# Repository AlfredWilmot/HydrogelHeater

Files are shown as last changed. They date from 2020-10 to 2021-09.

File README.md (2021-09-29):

# Overview of temperature controller hardware
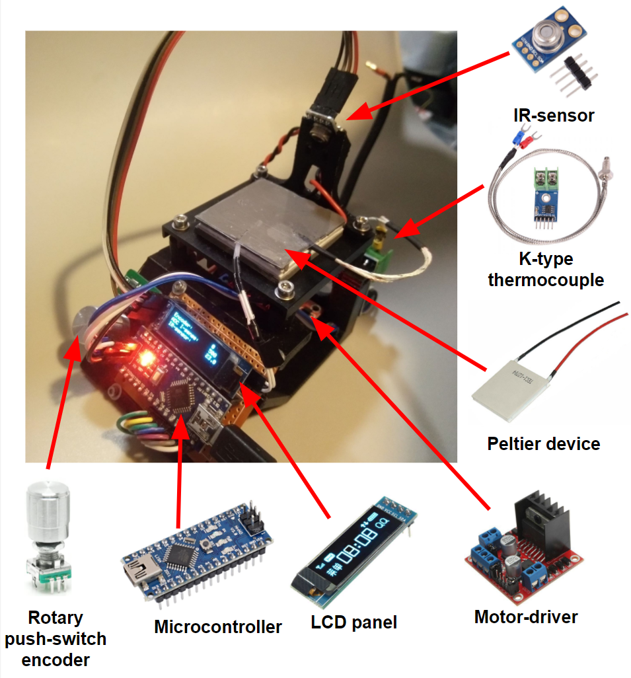
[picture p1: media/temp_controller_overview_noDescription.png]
 

[Click to see video showing visualization of system control varialbles during use.](https://drive.google.com/file/d/1k_EgCX9lhL9ZffbRWtTjD1a9hdL3mkuH/view?usp=sharing)

# Use of temperature controller for stimuli-responsive hydrogel research

| Experimental set-up | Close-up of activated temperature-sensitive hydrogel (20x speed) driven by temperature controller|
---|---
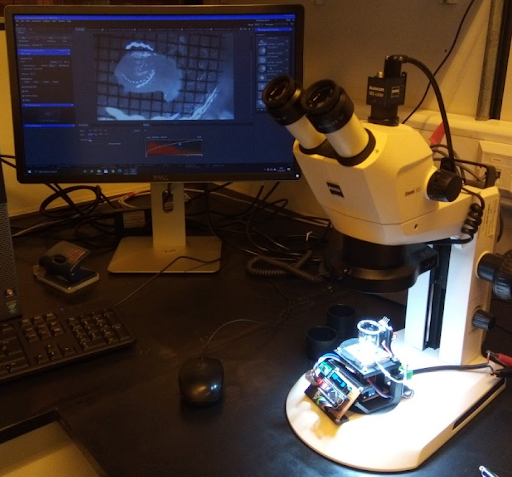
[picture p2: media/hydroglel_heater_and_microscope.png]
 |

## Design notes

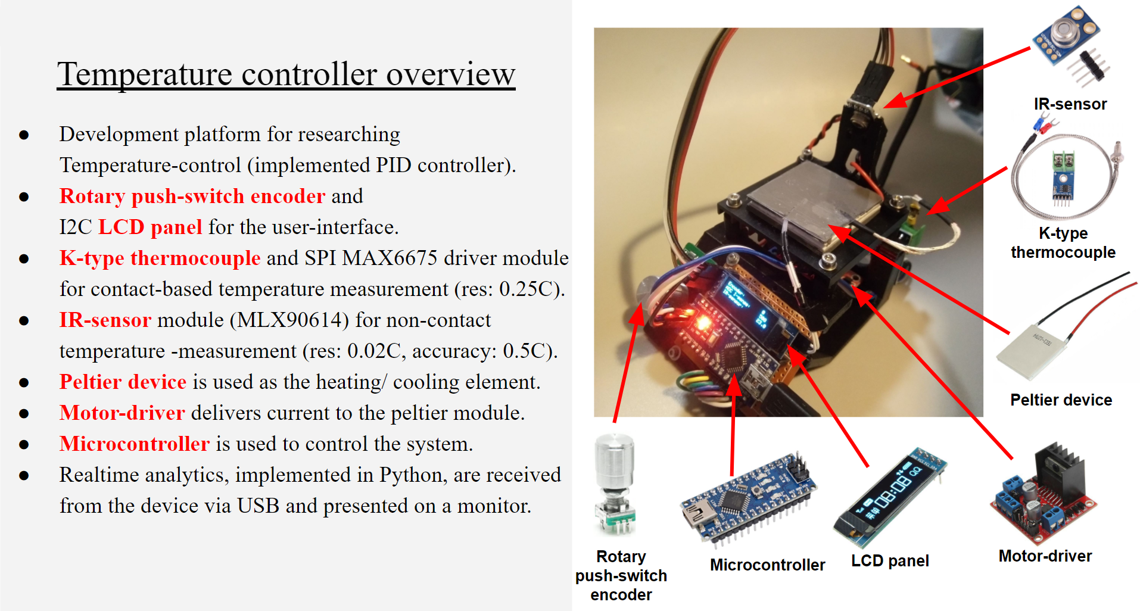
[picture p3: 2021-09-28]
media/temp_controller_overview.png

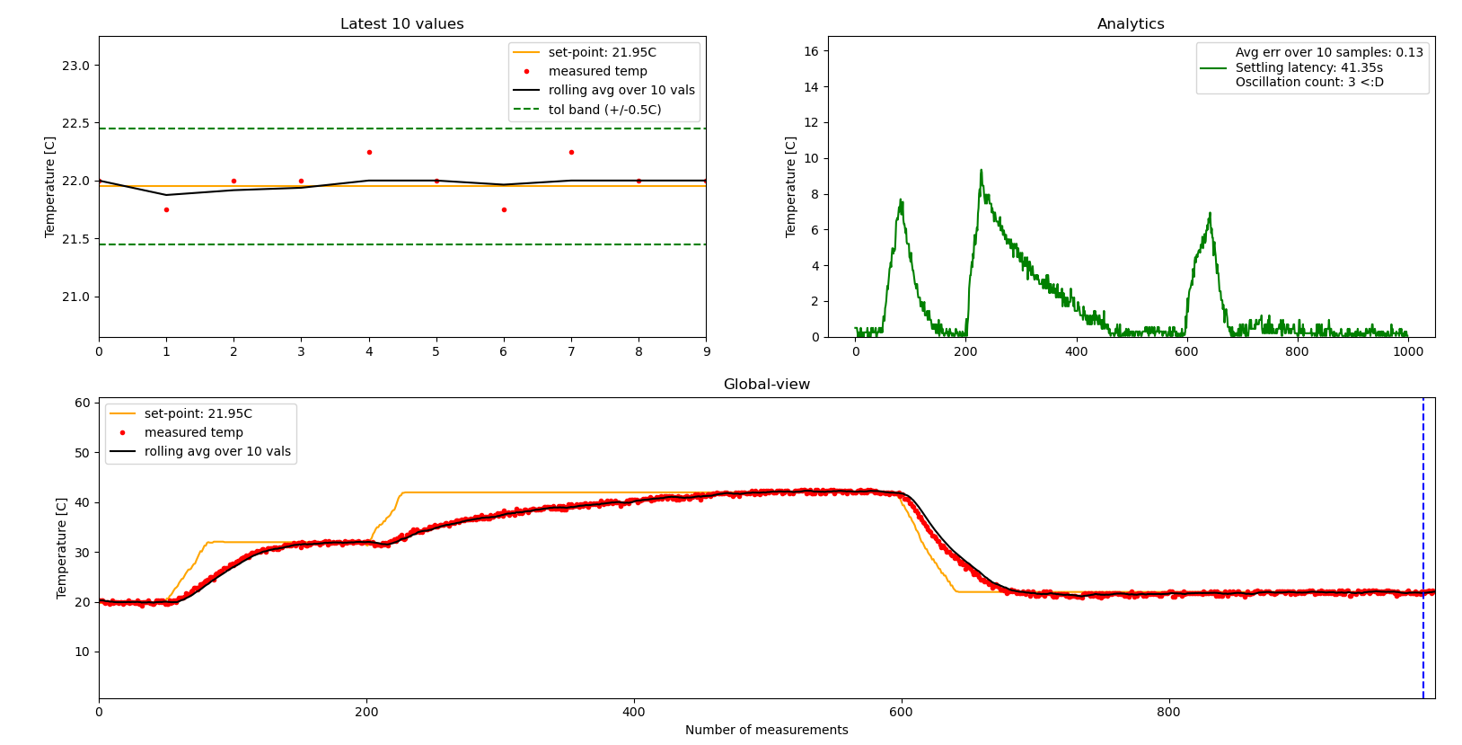
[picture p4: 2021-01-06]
data_analysis/pics/06_01_2021/PID_control_with_k_type.PNG

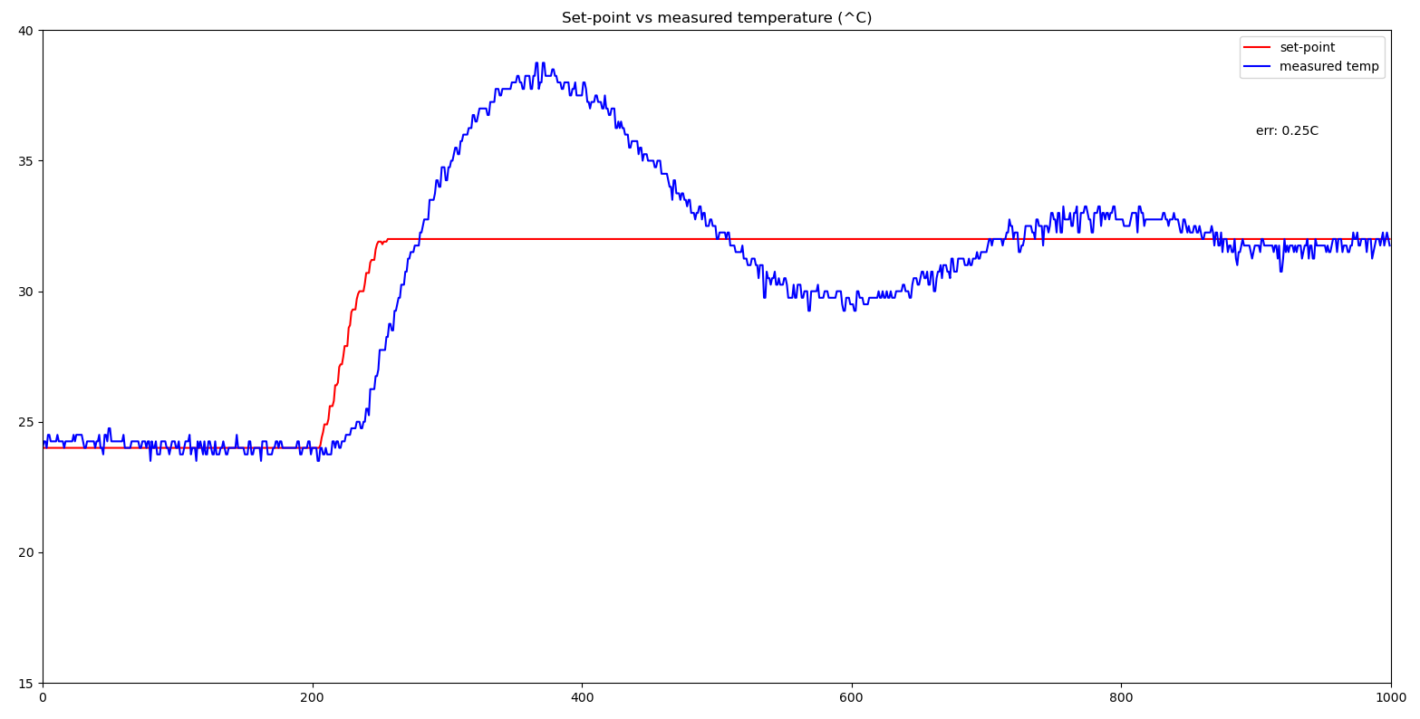
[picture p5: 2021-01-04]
data_analysis/pics/04_01_2021/24_to_32_k_type_cumulative_err.PNG

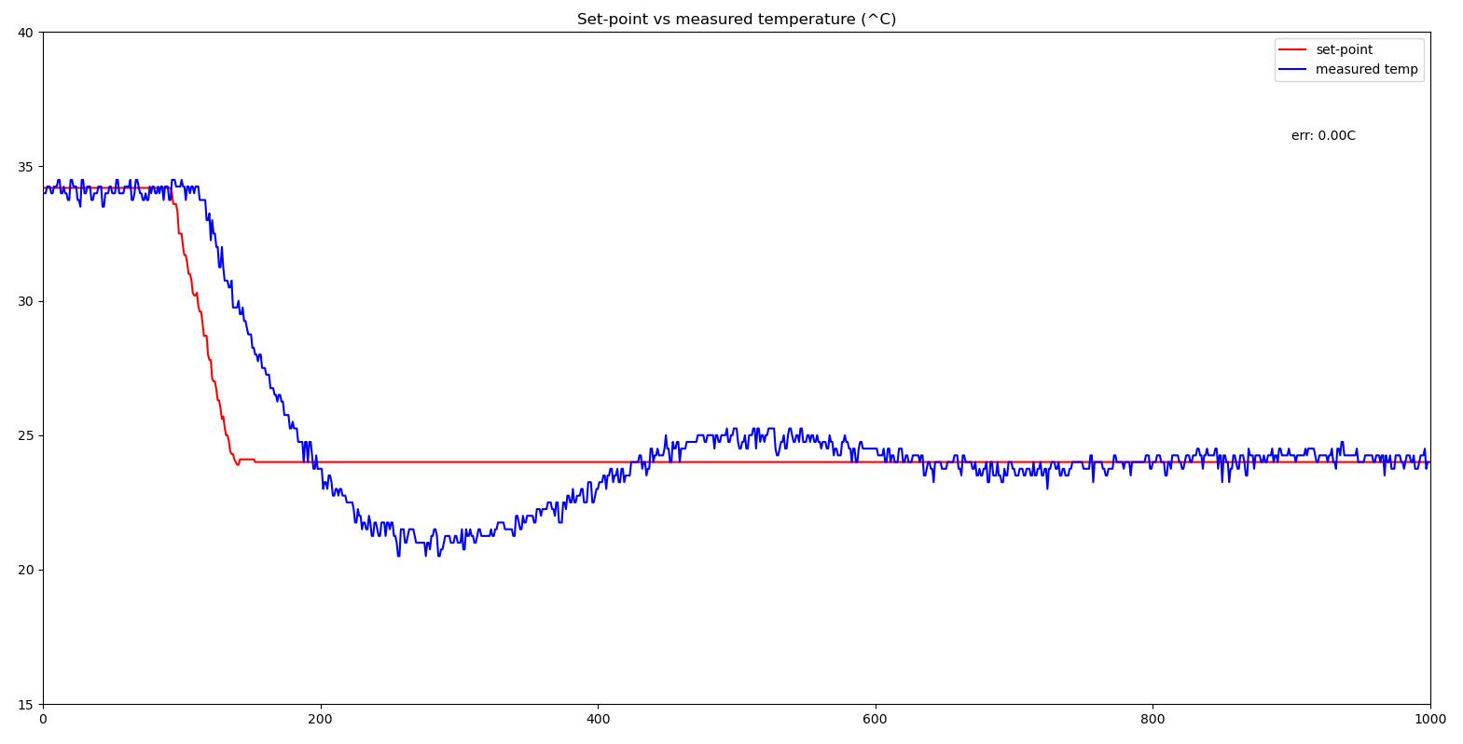
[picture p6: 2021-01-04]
data_analysis/pics/04_01_2021/32_to_24_k_type_cumulative_err.PNG

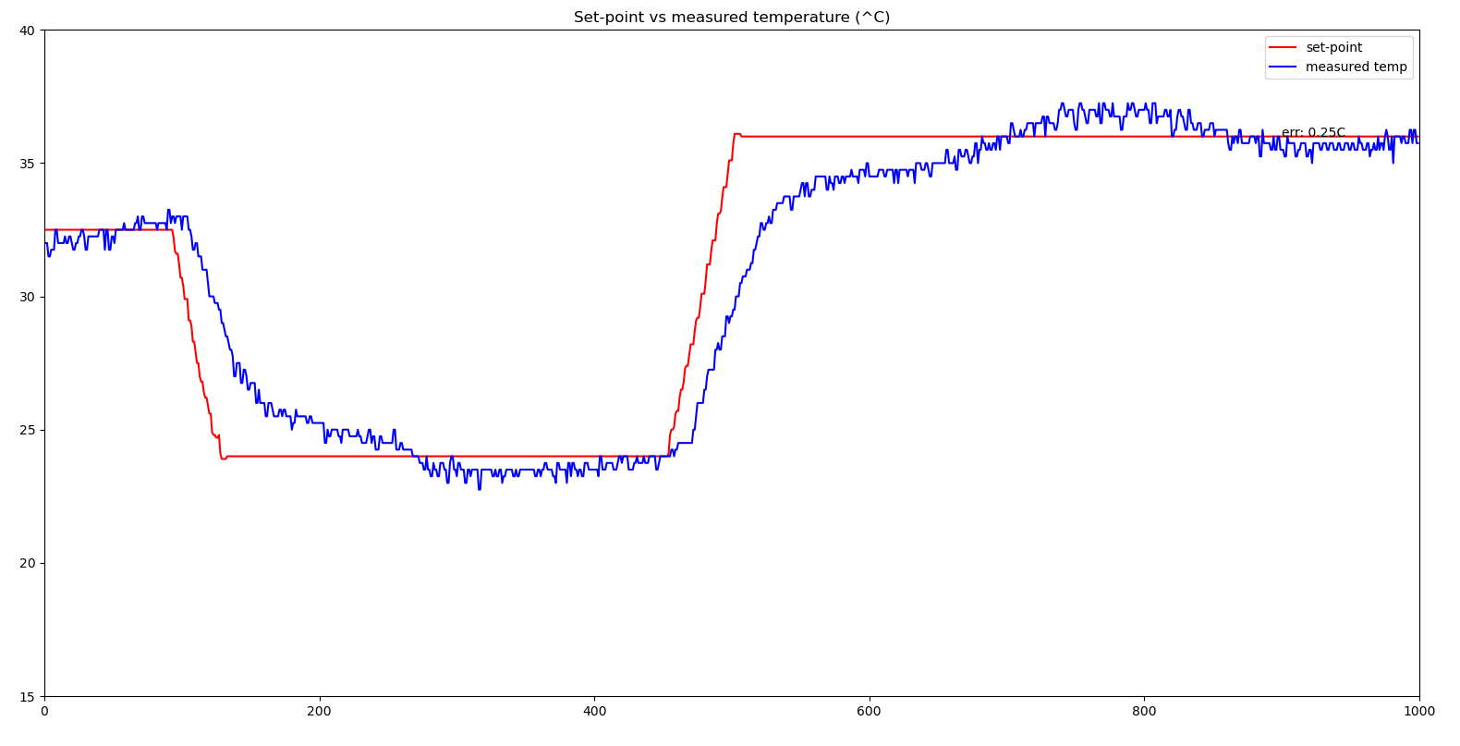
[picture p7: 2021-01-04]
data_analysis/pics/04_01_2021/32_to_24_to_36_kType_ImprovedCumulativeErr.PNG

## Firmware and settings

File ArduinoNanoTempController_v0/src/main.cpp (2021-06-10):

#include <Arduino.h>
#include "my_sensors.h"
#include "Adafruit_SSD1306.h"
#include "Adafruit_GFX.h"

// I2C IR sensor libs
#include "Wire.h"
#include "Adafruit_MLX90614.h"
/* Reference code taken from: https://miliohm.com/non-contact-temperature-sensor-mlx90614-arduino-tutorial/ */
Adafruit_MLX90614 IR_sense = Adafruit_MLX90614();


/*TODO: 
    > Add more indicator LEDs to the board for diagnostics.
    > Can also add information into classes from datasheets to also consider sensor accuracy/ precision.
*/

/* Resources for setting-up Ardunio programming in VS-Code:

-> Tutorial for settin-up PlatformIO for Arduino programming  (https://www.youtube.com/watch?v=dany7ae_0ks) 
-> Explore config files for different MCUs; not jsut Arduino  (https://platformio.org/boards)
-> Config settings for Arduino Nano                           (https://docs.platformio.org/en/latest/boards/atmelavr/nanoatmega328.html)

*/

// Allocating the A0 and A7 ADC pins to the NTC thermistor and I-sense monitor, respectively.
//NTC_thermistor my_ntc(Arduino_h::A0);
//I_sensor INA283(Arduino_h::A7, 10);

// Setup encoder push-button
EncoderPushButton EC11(2,3,4);
void encoder_ISR_handler()
{
  EC11.encoder_handler();
}


//Arduino_h::attachInterrupt(digitalPinToInterrupt(2), EC11.read_encoder_val(), CHANGE);

  //attachInterrupt(digitalPinToInterrupt(IN_B), test, CHANGE);
  //attachInterrupt(digitalPinToInterrupt(SW), test, RISING);


// Setting up the LCD
#define SCREEN_WIDTH 128 // OLED display width, in pixels
#define SCREEN_HEIGHT 32 // OLED display height, in pixels
#define OLED_RESET     4 // Reset pin # (or -1 if sharing Arduino reset pin)
Adafruit_SSD1306 display(SCREEN_WIDTH, SCREEN_HEIGHT, &Wire, OLED_RESET);

// Setting up the pins for the L298N motor-driver (used to drive the peltier element)
#define IN_1 8
#define IN_2 7
#define EN_A 6

// NOTE: switched pins 10 and 9 in code b/c I am too lazy to change the hardware
#define IN_3 10
#define IN_4 9

// pin 11 is used for SPI, so just couple PWM output of EN_A pin to EN_B (should do this for the IN pins too)
//#define EN_B 11

// Setting up SPI-based K-type thermocouple (uses MAX6675 chip)
K_type_couple MAX6675(MAX6675_CS);


//target temperature designated by the user
float set_point = 0.0;
// read temperature is determined by the sensor being used
float read_temperature = 0.0;

// value used to drive the output current through the peltier device [0,255]
int output_signal = 0;

// other menu control variables
int toggle_sense = 0;
int prev_state = EC11.get_state();


              


/* ------------------------------------------------------------------------------------------- */
/* -------------------------------------- ONE-TIME SETUP-------------------------------------- */
/* ------------------------------------------------------------------------------------------- */
void setup()
{

  // setup bottom peltier device
  pinMode(EN_A,OUTPUT);
  pinMode(IN_1,OUTPUT);
  pinMode(IN_2,OUTPUT);

  // setup top peltier device
  pinMode(IN_3,OUTPUT);
  pinMode(IN_4,OUTPUT);

  // Setup serial comms.
  Serial.begin(9600);
  pinMode(LED_BUILTIN,OUTPUT);

  // I2C preamble for OLED display.
  if(!display.begin(SSD1306_SWITCHCAPVCC, 0x3C)) { // Address 0x3C for 128x32
    Serial.println(F("SSD1306 allocation failed"));
    for(;;); // Don't proceed, loop forever
  }

  // Preparing display
  display.display();
  delay(1000);
  display.clearDisplay();
  display.setTextSize(1);
  display.setTextColor(SSD1306_WHITE); // Draw white text
  display.setCursor(0, 0);     // Start at top-left corner
  //display.cp437(true);         // Use full 256 char 'Code Page 437' font


  //set up Interrupts on encoder pins
  attachInterrupt(digitalPinToInterrupt(2), encoder_ISR_handler, CHANGE);
  attachInterrupt(digitalPinToInterrupt(3), encoder_ISR_handler, CHANGE); 
  attachInterrupt(digitalPinToInterrupt(4), encoder_ISR_handler, CHANGE); 
  //initialize the setpoint to equal the ambient temperature of the thermocouple.
  set_point = MAX6675.read();

}

/* ------------------------------------------------------------------------------------------- */
/* ---------------------------------------- MAIN LOOP ---------------------------------------- */
/* ------------------------------------------------------------------------------------------- */
void loop()
{

  // sample the encoder counter so the SP can be adjusted in steps of 0.1C.
  set_point += float(EC11.get_turn_count())/10;

  // threshold the set-point
  set_point > 100 ? set_point = 100: set_point = set_point;
  set_point < 0 ? set_point = 0: set_point = set_point;
  
  
  /*
    ----
    MENU
    ----

    > Overview screen
    > encoder button press -> go to "config submenu" -> can configure temperature sensor used, temperature resolution (fine [0.1], coarse [1.0], v_coarse [5.0]), adjust PID params.
    > Rotate encoder (adjusts set-point based on variables set in the config menu)
  
  */


  /*Display analytics*/ 
  // show data on OLED 128x32 display
  display.clearDisplay();

  display.setCursor(0, 0);
  display.print("Encoder: ");
  display.setCursor(100, 0);
  display.print(set_point,1);

  // display.setCursor(0, 10);
  // display.print("ADC I-sense: ");
  // display.setCursor(100, 10);
  // display.print(int(INA283.read()));

  display.setCursor(0, 10);
  display.print("Driving signal: ");
  display.setCursor(100, 10);
  display.print(output_signal);


  if (EC11.get_state() == btn_push and prev_state != btn_push)
  {
    toggle_sense^=1;
    prev_state = btn_push;
  }
  else if (EC11.get_state() != btn_push)
  {
    prev_state = EC11.get_state();
  }
  
  if (toggle_sense)
  {
  display.setCursor(0, 20);
  display.print("IR-sensor: ");
  display.setCursor(100, 20);
  read_temperature = IR_sense.readObjectTempC();
  display.print(read_temperature, 1);
  }
  else
  {
  display.setCursor(0, 20);
  display.print("k-type: ");
  display.setCursor(100, 20);
  read_temperature = MAX6675.read();
  display.print(read_temperature,1);
  }
  
  display.display(); 


  /*-------------------*/
  /* MAIN CONTROL LOOP */
  /*-------------------*/

  //output_signal = rolling_average_controller(set_point, read_temperature);
  //output_signal = cumulative_error_compensation(set_point, read_temperature);
  output_signal = PID_loop(set_point, read_temperature);

  //move motor CW if encoder val > 0, CCW if < 0, and stop if == 0.
  if (output_signal > 0)
  {
    digitalWrite(IN_1, HIGH);
    digitalWrite(IN_2, LOW);
    digitalWrite(IN_3, HIGH);
    digitalWrite(IN_4, LOW);
  }
  else if (output_signal < 0)
  {
    digitalWrite(IN_1, LOW);
    digitalWrite(IN_2, HIGH);
    digitalWrite(IN_3, LOW);
    digitalWrite(IN_4, HIGH);
  }
  else
  {
    digitalWrite(IN_1, LOW);
    digitalWrite(IN_2, LOW);
    digitalWrite(IN_3, LOW);
    digitalWrite(IN_4, LOW);
  }
  

  // feed current to peltier device
  analogWrite(EN_A, abs(output_signal));
  
  //transmit data over serial port
  Serial.println(set_point);
  Serial.println(read_temperature);
  Serial.println(output_signal);
  }

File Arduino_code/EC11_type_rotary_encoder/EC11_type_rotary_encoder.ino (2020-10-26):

/*
  Rotary encoder used:
  https://tech.alpsalpine.com/prod/e/html/encoder/incremental/ec11/ec11b15242b1.html

  Reference material:
  https://dronebotworkshop.com/rotary-encoders-arduino/
  
*/

// rotary encocer pins
#define IN_A 2  //pulse-train A
#define IN_B 3  //pulse-train B
#define SW 4    //momentary switch, D4
#define LED 13    //on-board indicator LED

int count = 0;  //count pulses
int IN_A_new;   
int IN_A_old;

void setup() {
  
  //configuring internal pup resistors (20k to 5V)
  pinMode(SW, INPUT_PULLUP); 
  pinMode(IN_A, INPUT_PULLUP); 
  pinMode(IN_B, INPUT_PULLUP); 
  pinMode(LED, OUTPUT);

  //start serial connection
  Serial.begin(9600);

  //assign the initial state of the IN_A pin to IN_A_old
  IN_A_old = digitalRead(IN_A);
  
}

void loop() {

  /*---------------------------------------*/
  //read the push-button state
  int sensorVal = digitalRead(SW);

  //update indicator LED
  if (sensorVal == HIGH) 
  {
    digitalWrite(LED, LOW);
  } 
  else 
  {
    digitalWrite(LED, HIGH);
  }
  /*---------------------------------------*/

  IN_A_new = digitalRead(IN_A);
  
  if (IN_A_new != IN_A_old)
  { 
    if (digitalRead(IN_B) != IN_A_new) 
    { 
      // Encoder is rotating CCW
      count --;
      digitalWrite(LED, HIGH);
      delay(100);
      digitalWrite(LED, LOW);
      delay(100);
     } 
     else 
     {
      // Encoder is rotating CW
      count ++;
      digitalWrite(LED, HIGH);
      delay(100);
      digitalWrite(LED, LOW);
      delay(100);
      digitalWrite(LED, HIGH);
      delay(100);
      digitalWrite(LED, LOW);
     }






  }

  
}

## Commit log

2020-05-29 Initial PCB files
    [peltier_driver_pcb.kicad_pcb, peltier_driver_pcb.sch]
2020-05-29 added I-sense IC and 128x32 OLED footprint
    [peltier_driver_pcb.kicad_pcb, peltier_driver_pcb.sch]
2020-05-29 added cad files to user-made PCB footprints
    [female_header_a-bl254-eg-g04d.stp, female_header_a-bl254-eg-g15d.stp, peltier_driver_pcb.kicad_pcb]
2020-05-29 properly saved 3D models to footprint files
    [peltier_driver_pcb.kicad_pcb]
2020-05-30 updating PCB
    [peltier_driver_pcb.kicad_pcb, peltier_driver_pcb.sch]
2020-05-31 single Pt1000, wheatstone bridge diff amplifier
    [peltier_driver_pcb.kicad_pcb, peltier_driver_pcb.sch]
2020-06-01 some tweaks
    [peltier_40_40_x.step, peltier_driver_pcb.kicad_pcb, peltier_driver_pcb.sch]
2020-06-02 I-source for Pt1000, fixed I2C level mismatch, added mounting holes
    [peltier_driver_pcb.kicad_pcb, peltier_driver_pcb.sch]
2020-06-03 resettable fuse, rearranged board for neatness
    [peltier_driver_pcb.kicad_pcb, peltier_driver_pcb.sch]
2020-06-03 added break-out for remaining Arduino pins
    [peltier_driver_pcb.kicad_pcb, peltier_driver_pcb.sch]
2020-06-06 some scripting to calculate values for NTC circuit and conversion
    [GA10K4A1A_RT_table.csv]
2020-06-07 Exploring thermistor error calculations
2020-06-07 starting to implement requested changes
    [peltier_driver_pcb.sch]
2020-06-10 ltspice sims and modular pcb v1
    [peltier_driver_pcb.kicad_pcb, peltier_driver_pcb.sch]
2020-06-10 v1 PCB ready for show
    [peltier_driver_pcb.kicad_pcb, peltier_driver_pcb.sch]
2020-06-15 testing INA283 in LTspice
    [ina283 test circuit.dsn]
2020-06-16 updating gerber files for UI PCB
    [peltier_driver_pcb-B_Cu.gbr, peltier_driver_pcb-B_Mask.gbr, peltier_driver_pcb-B_Paste.gbr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]
2020-06-16 better arduino ftprnt lib, first iteration of shield PCBs
    [Arduino_Nano_shield-B_Cu.gbr, Arduino_Nano_shield-B_Mask.gbr, Arduino_Nano_shield-B_Paste.gbr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]
2020-06-17 matching PCB dimensions to each other
    [Arduino_Nano_shield-B_Cu.gbr, Arduino_Nano_shield-B_Mask.gbr, Arduino_Nano_shield-B_Paste.gbr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]
2020-06-17 final touches for second design iteration
    [Arduino_Nano_shield-B_Cu.gbr, Arduino_Nano_shield-B_Mask.gbr, Arduino_Nano_shield-B_Paste.gbr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]
2020-07-03 initializing workspace for my home coil system
    [Arduino_Nano_shield-B_Cu.gbr, Arduino_Nano_shield-B_Mask.gbr, Arduino_Nano_shield-B_Paste.gbr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]
2020-07-18 experimental complimentary pwm-driven VCCS
2020-07-18 measure voltage from T-sense and display via serial, need to convert to temp
2020-07-19 display of uncalibrated temperature; most accurate between [25C, 100C]
2020-11-07 implemented overhead IR-sensor
2020-11-29 starting to implement PID loop and therocouple
2020-11-29 fixed multiple declaration issue with PID stuff
    [main.cpp]
2020-12-13 crude non-blocking timer for non-blocking sampling of thermocouple
2020-12-14 encoder more or less functions
2020-12-14 slightly unstable when encoder is spammed, but functional
    [main.cpp]
2020-12-14 Arduino delays + ISRs = deadlock, don't mix these two
2020-12-14 encoder behaves and can toggle between two temp sensors using btn press
2020-12-14 basic PID temperature control-- needs to adapt to bleeding effects
2020-12-15 deserializing arduino output to plot/ inspect data
2020-12-15 plotting both set-point and measured temperature
2021-01-03 Tweaking PID gains, and setting soft limit
2021-01-03 slightly better err handling, but still need to unplug/ replug usb cable after closing port in software
2021-01-04 cumulative error controller seems to hold a position with high precision but takes a while to reach the SP
    [main.cpp]
2021-01-05 ~fixed tol band tracking issue
    [plot_arduino_serial_v0.py]
2021-01-05 fixed it properly (but lazily imo)
    [plot_arduino_serial_v0.py]
2021-01-05 implemented my own PID controller
2021-01-06 added settling latency & oscillator counter to analytics plot
    [plot_arduino_serial_v0.py]
2021-01-06 nice rolling average over n-samples
2021-06-10 something to do with PID loop
2021-09-28 overview image of temperature controller hardware
